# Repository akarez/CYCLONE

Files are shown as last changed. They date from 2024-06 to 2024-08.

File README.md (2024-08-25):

<h1 align="center">CYCLONE</h1>

<p align="center">
  The CYCLONE is a temperature controlled dual-fan driver for small space cooling applications. 
  It features an STM32F030 microcontroller, MCP9808 temperature sensor, and FET drivers connected to PWM pins in the MCU.
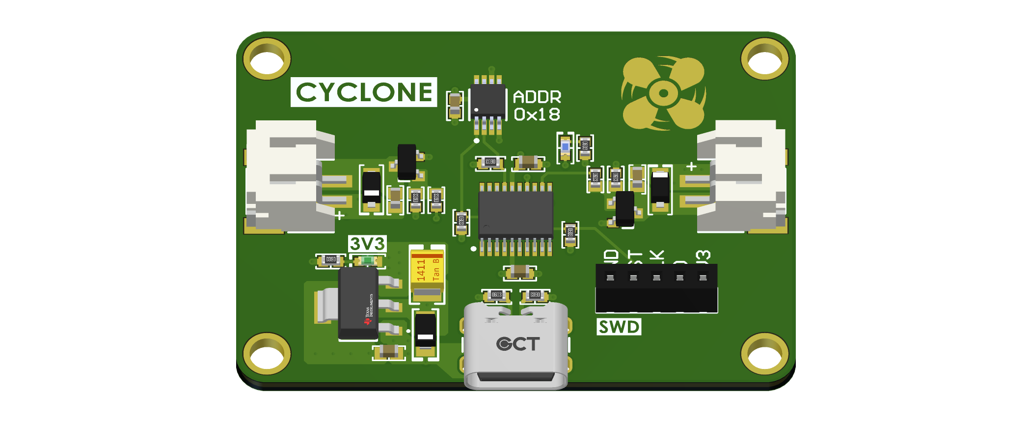
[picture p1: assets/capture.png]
cyclone 3D render
  
</p>

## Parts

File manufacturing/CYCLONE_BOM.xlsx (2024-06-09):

Comment | Description | Designator | Footprint | Quantity | JLCPCB Part #
1 µ | CAP CER 1UF 16V X7R 0603 | C1, C5, C7 | CAP 0603_1608 | 3 | GCM188R71C105KA64J
33 µF | CAP TANT 33UF 20% 16V 1411 | C2 | CAP POL 1411_3528 | 1 | C1953574
0.1 µ | CAP CER 0.1UF 50V X7R 0603 | C3, C4, C6 | CAP 0603_1608 | 3 | C91183
VTVS5V0ASMF-M3-08 | TVS DIODE 5V 8.9V DO219AB | D1 | SMF DO-219AB | 1 | C1982736
US1DWF-7 | DIODE GEN PURP 200V 1A SOD123F | D2, D3 | SOD123F | 2 | C64904
Green | LED GREEN CLEAR SMD | D4 | LED 0603_1608 GREEN | 1 | C473820
Blue | LED BLUE CLEAR CHIP SMD | D5 | LED 0603_1608 BLUE | 1 | C2837377
DMN62D0U-13 | MOSFET N-CH 60V 380MA SOT23 | IC1, IC2 | DIODES SOT-23-3 | 2 | C156342
USB4125-GF-A-0190 | USB-C (USB TYPE-C) Receptacle Connector 24 (6+18 Dummy) Position Surface Mount, Right Angle; Through Hole | J1 | FP-USB4125-GF-A-0190-MFG | 1 | C2927029
S2B-PH-SM4-TB(LF)(SN) | CONN HEADER SMD R/A 2POS 2MM | J2, J3 | JST S2B-PH-SM4-TB | 2 | C295747
5.1 k | RES 5.1K OHM 5% 1/10W 0603 | R1, R2 | RES 0603_1608 | 2 | C318133
10 k | RES 10K OHM 0.1% 1/16W 0603 | R3, R5, R6, R7, R9 | RES 0603_1608 | 5 | C667640
220 | RES SMD 220 OHM 0.5% 1/10W 0603 | R4, R8 | RES 0603_1608 | 2 | C103414
1 k | RES SMD 1K OHM 0.1% 1/16W 0603 | R10, R11 | RES 0603_1608 | 2 | C176132
LM3940 | IC REG LDO 3.3V 1A SOT223 | U1 | FP-DCY0004A-IPC_C | 1 | C140319
STM32F030F4P6TR | RISC Microcontroller, 32-Bit, FLASH, CORTEX-M0 CPU, 48MHz, CMOS, PDSO20 | U2 | STM-TSSOP20_M | 1 | C89040
MCP9808T-E/MS | Serial Switch/Digital Sensor, 16 Bit(s), 1Cel, Square, Surface Mount | U3 | FP-C04-111-MFG | 1 | C129490

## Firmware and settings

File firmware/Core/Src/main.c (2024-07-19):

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
/* Includes ------------------------------------------------------------------*/
#include "main.h"

/* USER CODE BEGIN Includes */
#include "stdbool.h"
/* USER CODE END Includes */

/* USER CODE BEGIN PD */
#define MCP9808_ADDRESS (0x18 << 1)		/* check datasheet for address options. adjust as needed */
#define TEMPERATURE_THRESHOLD 24.44		/* 24.44 celsius/76 fahrenheit. adjust as needed */
#define FAN_ON_TIME_TICKS 1200  		/* fan on time in ticks / 0.1 seconds per tick */
/* USER CODE END PD */

I2C_HandleTypeDef hi2c1;
TIM_HandleTypeDef htim3;

/* USER CODE BEGIN PV */
bool fanStatus = false;  				/* fan running status */
bool timerRunning = false;  			/* timer running status */
float currentTemperature = 0.0;  		/* current temperature reading */
int timerCounter = 0;  					/* timer counter to keep track of elapsed time in ticks */
/* USER CODE END PV */

void SystemClock_Config(void);
static void MX_GPIO_Init(void);
static void MX_I2C1_Init(void);
static void MX_TIM3_Init(void);
/* USER CODE BEGIN PFP */
float MCP9808_GetTemperature(void);
void turnFanOn(void);
void turnFanOff(void);
/* USER CODE END PFP */

/**
 * @brief  The application entry point.
 * @retval int
 */
int main(void) {

	/* MCU Configuration--------------------------------------------------------*/

	/* Reset of all peripherals, Initializes the Flash interface and the Systick. */
	HAL_Init();

	/* Configure the system clock */
	SystemClock_Config();

	/* Initialize all configured peripherals */
	MX_GPIO_Init();
	MX_I2C1_Init();
	MX_TIM3_Init();
	/* USER CODE BEGIN 2 */
	// Start Timer 3 interrupt
	HAL_TIM_Base_Start_IT(&htim3);
	/* USER CODE END 2 */

	/* USER CODE BEGIN WHILE */
	while (1) {
		currentTemperature = MCP9808_GetTemperature();

		/* check if the temperature exceeds the threshold and timer is not running */
		if (currentTemperature >= TEMPERATURE_THRESHOLD && !timerRunning) {
			turnFanOn();
			timerRunning = true;
			timerCounter = 0;  /* reset the timer counter */
		}

		/* check if the temperature is below the threshold and timer is done */
		if (currentTemperature < TEMPERATURE_THRESHOLD && !timerRunning) {
			turnFanOff();
		}

		HAL_Delay(1000);
	}
	/* USER CODE END WHILE */

	/* USER CODE BEGIN 3 */
}

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
/* USER CODE BEGIN 4 */

/**
 * @brief Get the MCP9808 temperature reading in Celsius. This code is taken from
 * https://embeddedespresso.com/temperature-measurement-never-so-easy-with-stm32-and-mcp9808/
 * and wrapped into a function
 * @retval Float
 */
float MCP9808_GetTemperature() {
	uint8_t tempReg = 0x05u; /* Temperature register address */
	uint8_t dataReg[2]; /* Buffer for reading the register content */
	uint16_t dataRegLong; /* Variable used to store the whole register content */
	float tempVal = 0; /* Float variable used for storing the temperature value */
	float tempValDec; /* Float variable used for calculation of the decimal part */

	/* Address the temperature register */
	HAL_I2C_Master_Transmit(&hi2c1, MCP9808_ADDRESS, &tempReg, 1, 2000u);
	/* Read the temperature register content */
	HAL_I2C_Master_Receive(&hi2c1, MCP9808_ADDRESS | 0x01, dataReg, 2, 2000u);

	/* Compose the register content, regardless of the endianess */
	dataRegLong = ((dataReg[0] << 8u) | dataReg[1]);

	/* Extract the integer part from the fixed point value */
	tempVal = ((dataRegLong & 0x0FFF) >> 4);

	/* Extract decimal part */
	tempValDec = 0.0625;
	for (int i = 0; i < 4; i++) {
		tempVal += ((dataRegLong >> i) & 0x0001) * tempValDec;
		tempValDec *= 2u;
	}

	return tempVal;
}

/**
 * @brief Turn the fan on and update status
 */
void turnFanOn(void) {
	fanStatus = true;
	HAL_GPIO_WritePin(GPIOA, FAN1_Pin | FAN2_Pin | STAT_LED_Pin, GPIO_PIN_SET);
}

/**
 * @brief Turn the fan off and update status
 */
void turnFanOff(void) {
	fanStatus = false;
	HAL_GPIO_WritePin(GPIOA, FAN1_Pin | FAN2_Pin | STAT_LED_Pin, GPIO_PIN_RESET);
}

/**
 * @brief Timer 3 interrupt handler triggered every 100 milliseconds
 * @param htim: Timer handle pointer
 */
void HAL_TIM_PeriodElapsedCallback(TIM_HandleTypeDef *htim) {
	if (htim->Instance == TIM3) {
		if (timerRunning) {
			timerCounter += 1;
			if (timerCounter >= FAN_ON_TIME_TICKS) {
				timerRunning = false;
				timerCounter = 0;
			}
		}
	}
}
/* USER CODE END 4 */
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


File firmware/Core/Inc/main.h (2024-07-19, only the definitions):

#define STAT_LED_Pin GPIO_PIN_5
#define STAT_LED_GPIO_Port GPIOA
#define FAN1_Pin GPIO_PIN_6
#define FAN1_GPIO_Port GPIOA
#define FAN2_Pin GPIO_PIN_7
#define FAN2_GPIO_Port GPIOA
#define ALERT_Pin GPIO_PIN_1
#define ALERT_GPIO_Port GPIOB
#define SCL_Pin GPIO_PIN_9
#define SCL_GPIO_Port GPIOA
#define SDA_Pin GPIO_PIN_10
#define SDA_GPIO_Port GPIOA

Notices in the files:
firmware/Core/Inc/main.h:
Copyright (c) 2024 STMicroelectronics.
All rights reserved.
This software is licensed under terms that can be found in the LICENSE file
